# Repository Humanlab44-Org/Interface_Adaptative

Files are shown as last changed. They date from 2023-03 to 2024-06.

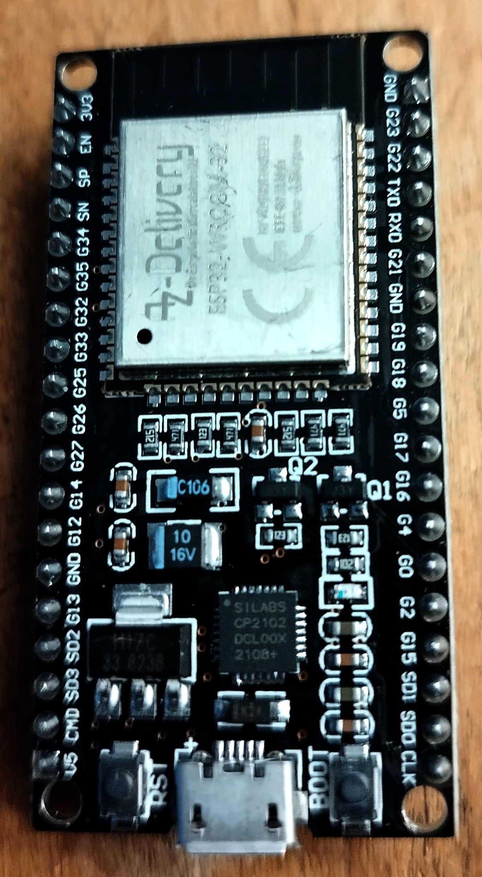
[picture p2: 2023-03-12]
Schema_circuit/esp32.jpg

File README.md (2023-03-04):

# Interface_Adaptative
## Contexte et définition du projet 

Nous projetons de construire une interface de jeux pour personnes aux gestes perturbés ou diminués. En effet, pour celles-ci l’utilisation d’un clavier ou d’une manette de jeux classique est difficile voire impossible à utiliser.  
Ce projet a pour but d’élaborer une première interface dévolue aux jeux vidéo et pouvant évoluer vers un objet de domotique 
## Objectif du projet 

Fourniture d’une première interface fonctionnelle de jeux 

Constitution d’un dossier avec : 

- La procédure d’utilisation, 
- La liste du matériel utilisé,  
- Les plans de fabrication, 
- Les schémas de câblage, 
- Le listing du programme 
- Formation des utilisateurs 
- Ouverture d’une discussion avec les utilisateurs pour l’évolution du projet

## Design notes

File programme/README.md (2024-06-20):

/*
Nom du fichier : readme.md
Auteur : Yann Cesbron  (yann@cesbron.org)
Date de création : 4 avril 2023
Licence :  Creative Commons BY-NC-SA
*/

# HandiPad est une interface de jeux/applications pour personnes aux gestes perturbés ou diminués.
- Ceci permettra l’utilisation d’un clavier/souris et/ou d’une manette de jeux classique.
- Ce programme est operationnel sur ESP32 Wroom ou Wroover. 
- il s'inscrit dans un projet qui a pour but d’élaborer une première interface dévolue aux jeux vidéo et d'autres usages.

- L'interface hardware sera decrite prochainement. Quelques elements sont toutefois disponibles ici: https://github.com/Humanlab44-Org/Interface_Adaptative

# LICENCE
CC-by-nc-sa (Attribution / Pas d’Utilisation Commerciale / Partage dans les mêmes conditions)

La licence CC-by-nc-sa 4.0 permet toute exploitation de l’œuvre (partager, copier, reproduire, distribuer, communiquer, réutiliser, adapter) par tous moyens, sous tous formats. Toutes les exploitations de l’œuvre ou des œuvres dérivées, sauf à des fins commerciales, sont possibles.

Les obligations liées à la licence sont de :
- créditer les créateurs de la paternité des œuvres originales, d’en indiquer les sources et d’indiquer si des modifications ont été effectuées aux œuvres (obligation d’attribution) ;
- ne pas tirer profit (gain direct ou plus-value commerciale) de l’œuvre ou des œuvres dérivées ;
- diffuser les nouvelles créations selon des conditions identiques (selon la même licence) à celles de l’œuvre originale (donc autoriser à nouveau les modifications et interdire les utilisations commerciales).

Cette licence interdit donc que les nouvelles dérivations de l’œuvre dérivée soient exploitées à des fins commerciales.

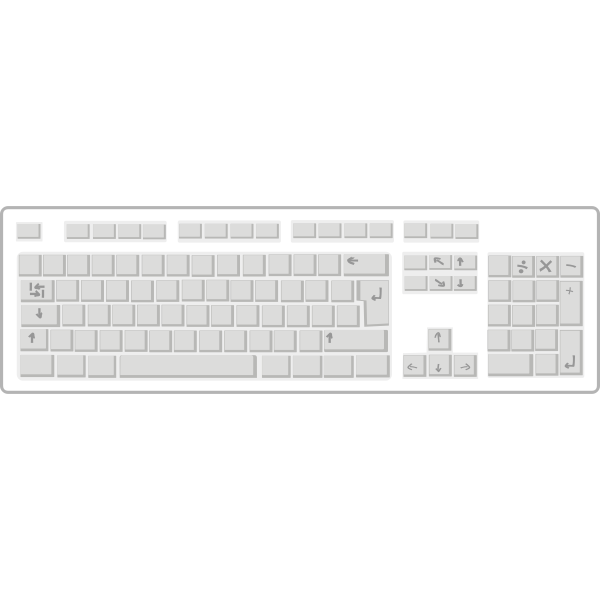
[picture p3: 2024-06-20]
programme/SDCard/img/blank_keyboards.png

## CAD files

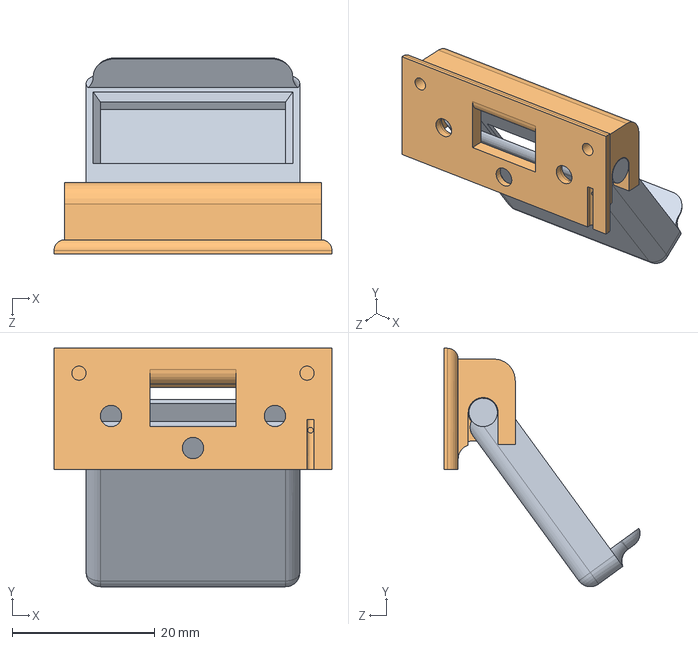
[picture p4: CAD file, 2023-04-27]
Montage3D/Afficheur/Assemblage6.SLDASM
39.0 x 33.5 x 27.5 mm
SupportAff6
Base6

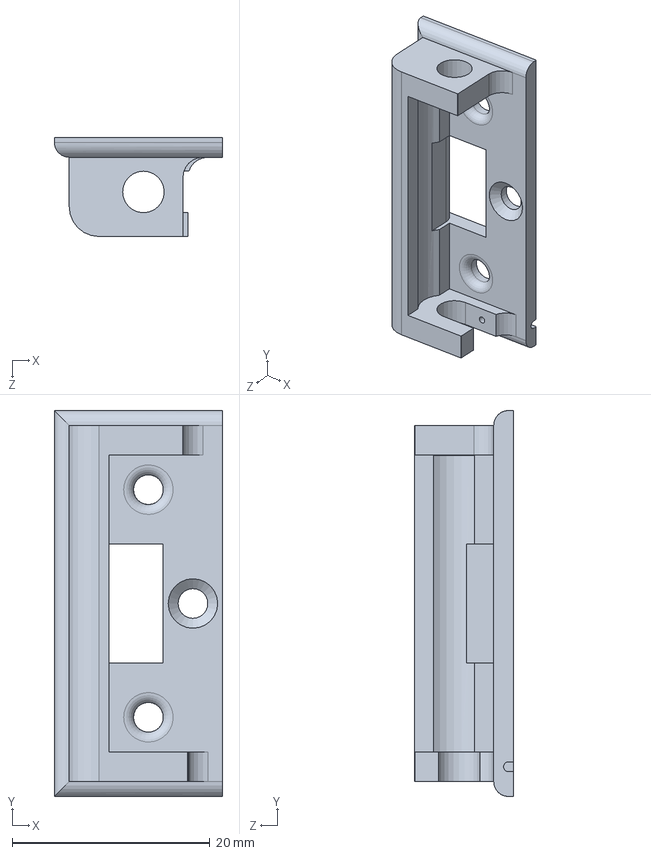
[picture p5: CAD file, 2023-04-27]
Montage3D/Afficheur/Base6.SLDPRT
17.0 x 39.0 x 10.0 mm

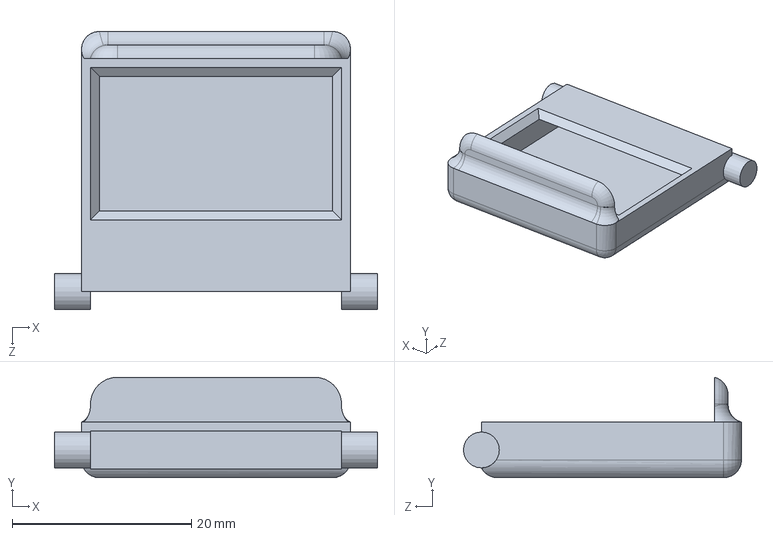
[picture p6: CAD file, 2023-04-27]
Montage3D/Afficheur/SupportAff6.SLDPRT
36.0 x 11.2 x 31.0 mm

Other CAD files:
Montage3D/Afficheur/Base6.STL
Montage3D/Afficheur/SupportAff6.STL

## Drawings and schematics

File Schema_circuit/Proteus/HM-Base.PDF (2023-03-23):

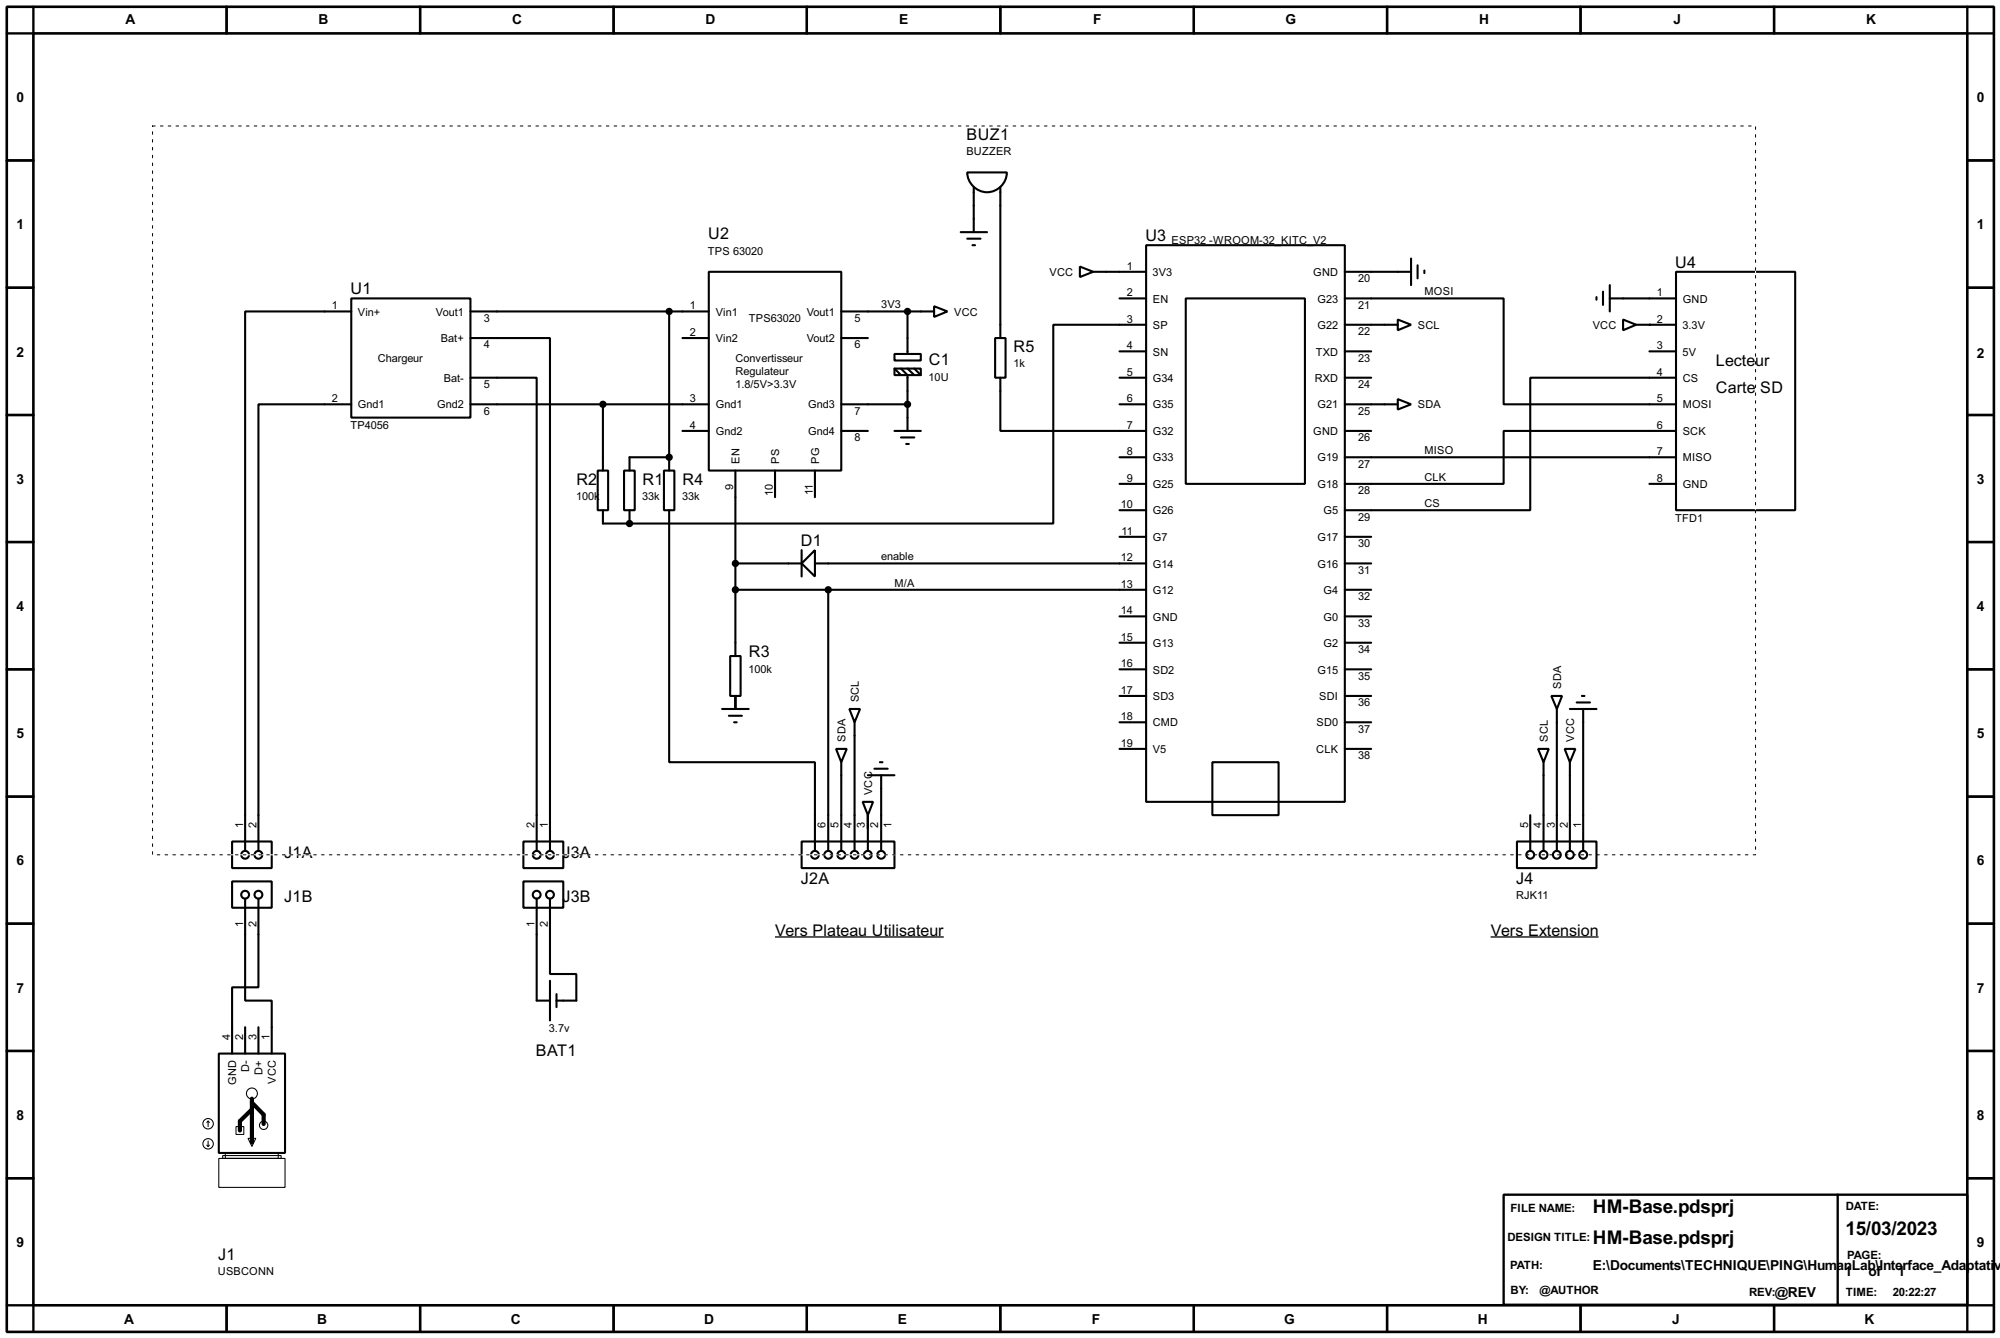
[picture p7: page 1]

BUZ1 BUZZER

2 | 3 Bat+

2 3 | Vout2 Convertisseur 1.8/5V>3.3V Regulateur Gnd1 Gnd3 Gnd2 Gnd4 | 6 Vin2

enable M/A | 31 G4

PAGE: HM-Base.pdsprj

FILE NAME:
DESIGN TITLE:HM-Base.pdsprj

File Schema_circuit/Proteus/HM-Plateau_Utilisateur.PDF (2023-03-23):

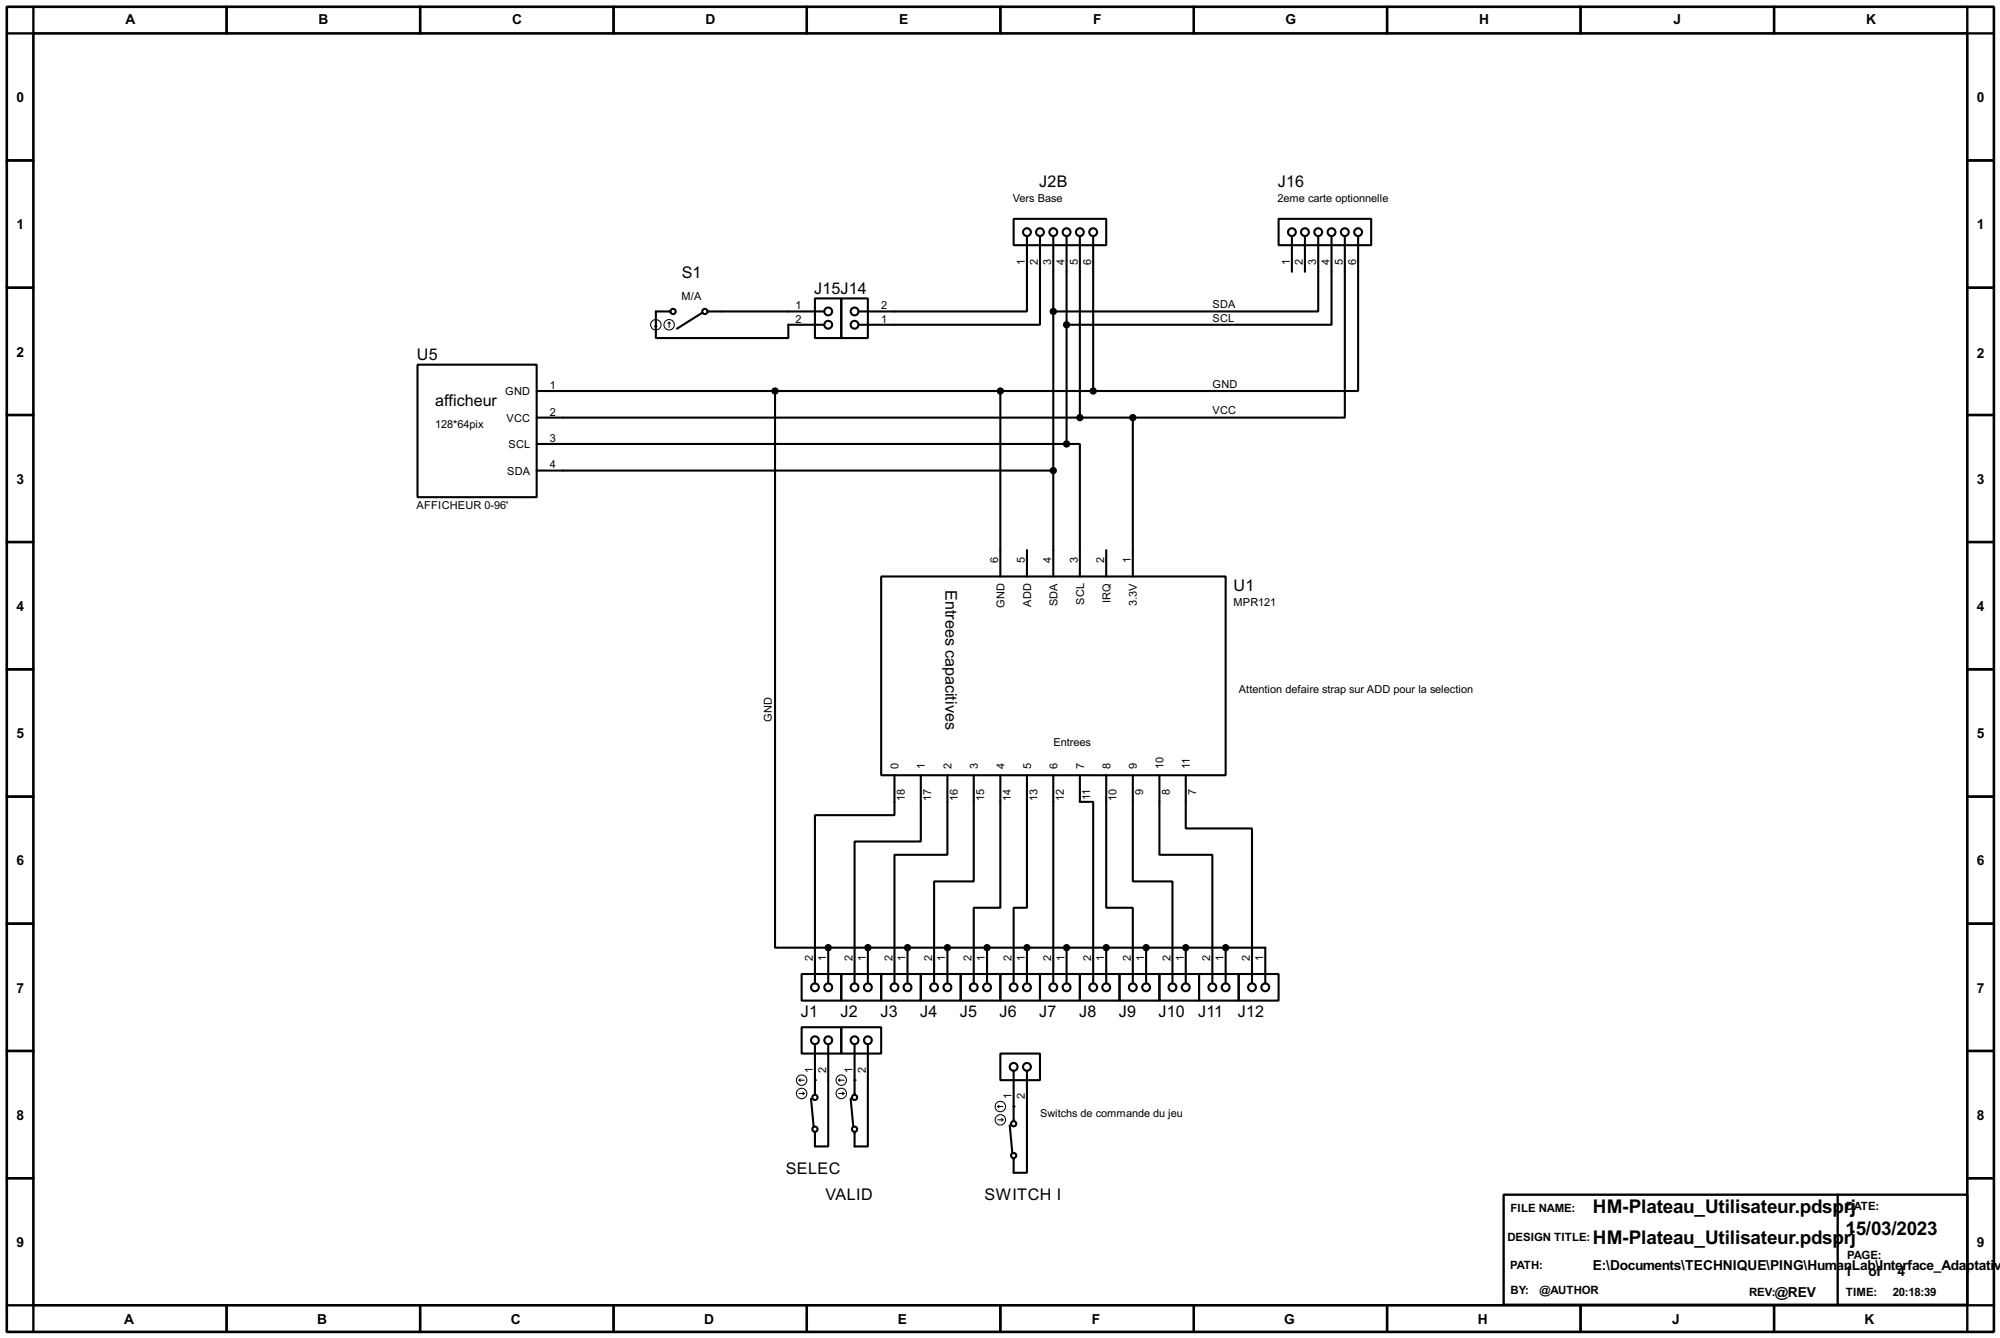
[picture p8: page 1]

1 VCC | | VCC afficheur 128*64pix

GND

2 SCL

3 SDA 4

Attention defaire strap sur ADD pour la selection

Switchs de commande du jeu

FILE NAME:
DESIGN TITLE:HM-Plateau_Utilisateur.pdsprj

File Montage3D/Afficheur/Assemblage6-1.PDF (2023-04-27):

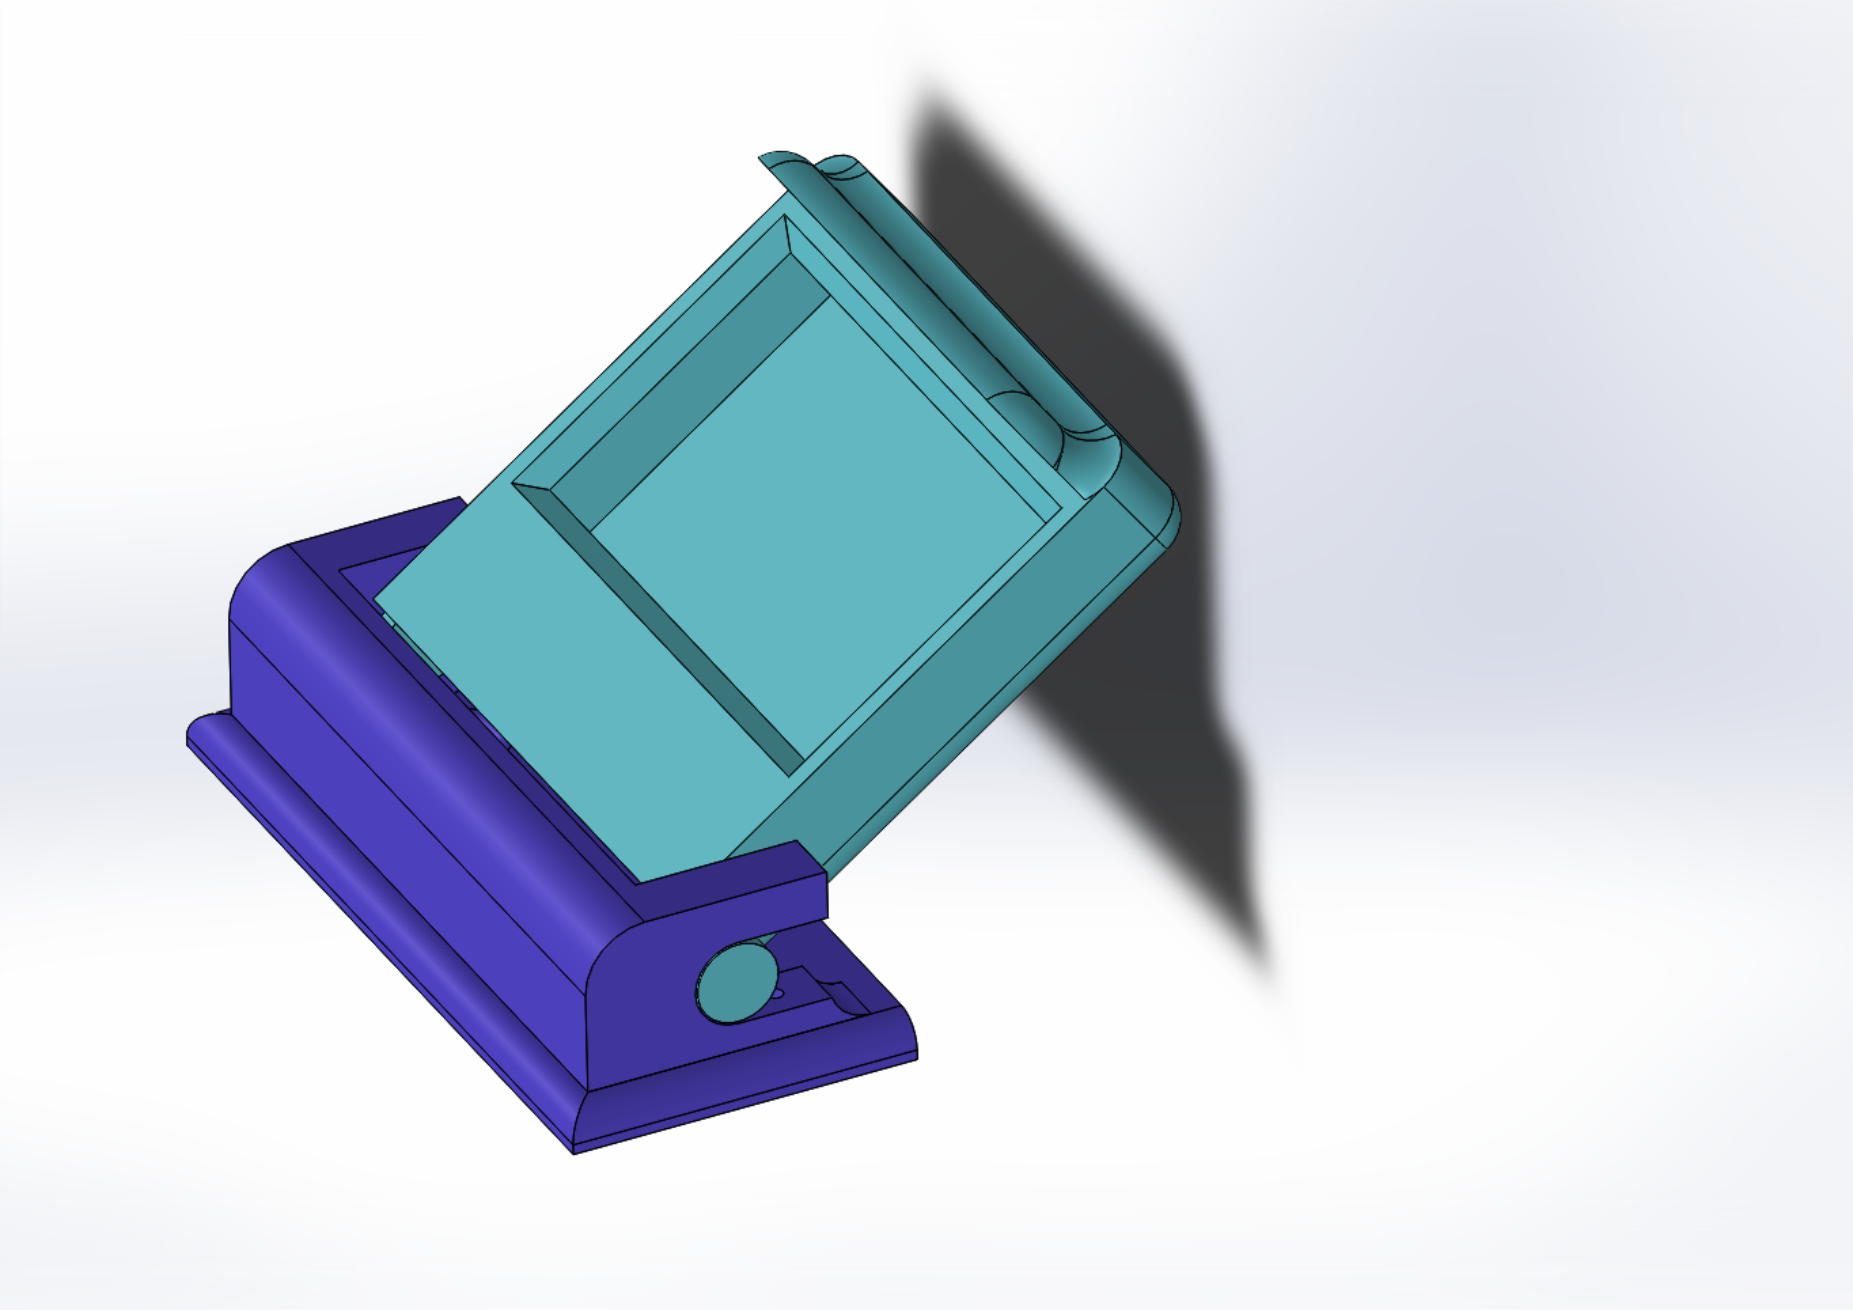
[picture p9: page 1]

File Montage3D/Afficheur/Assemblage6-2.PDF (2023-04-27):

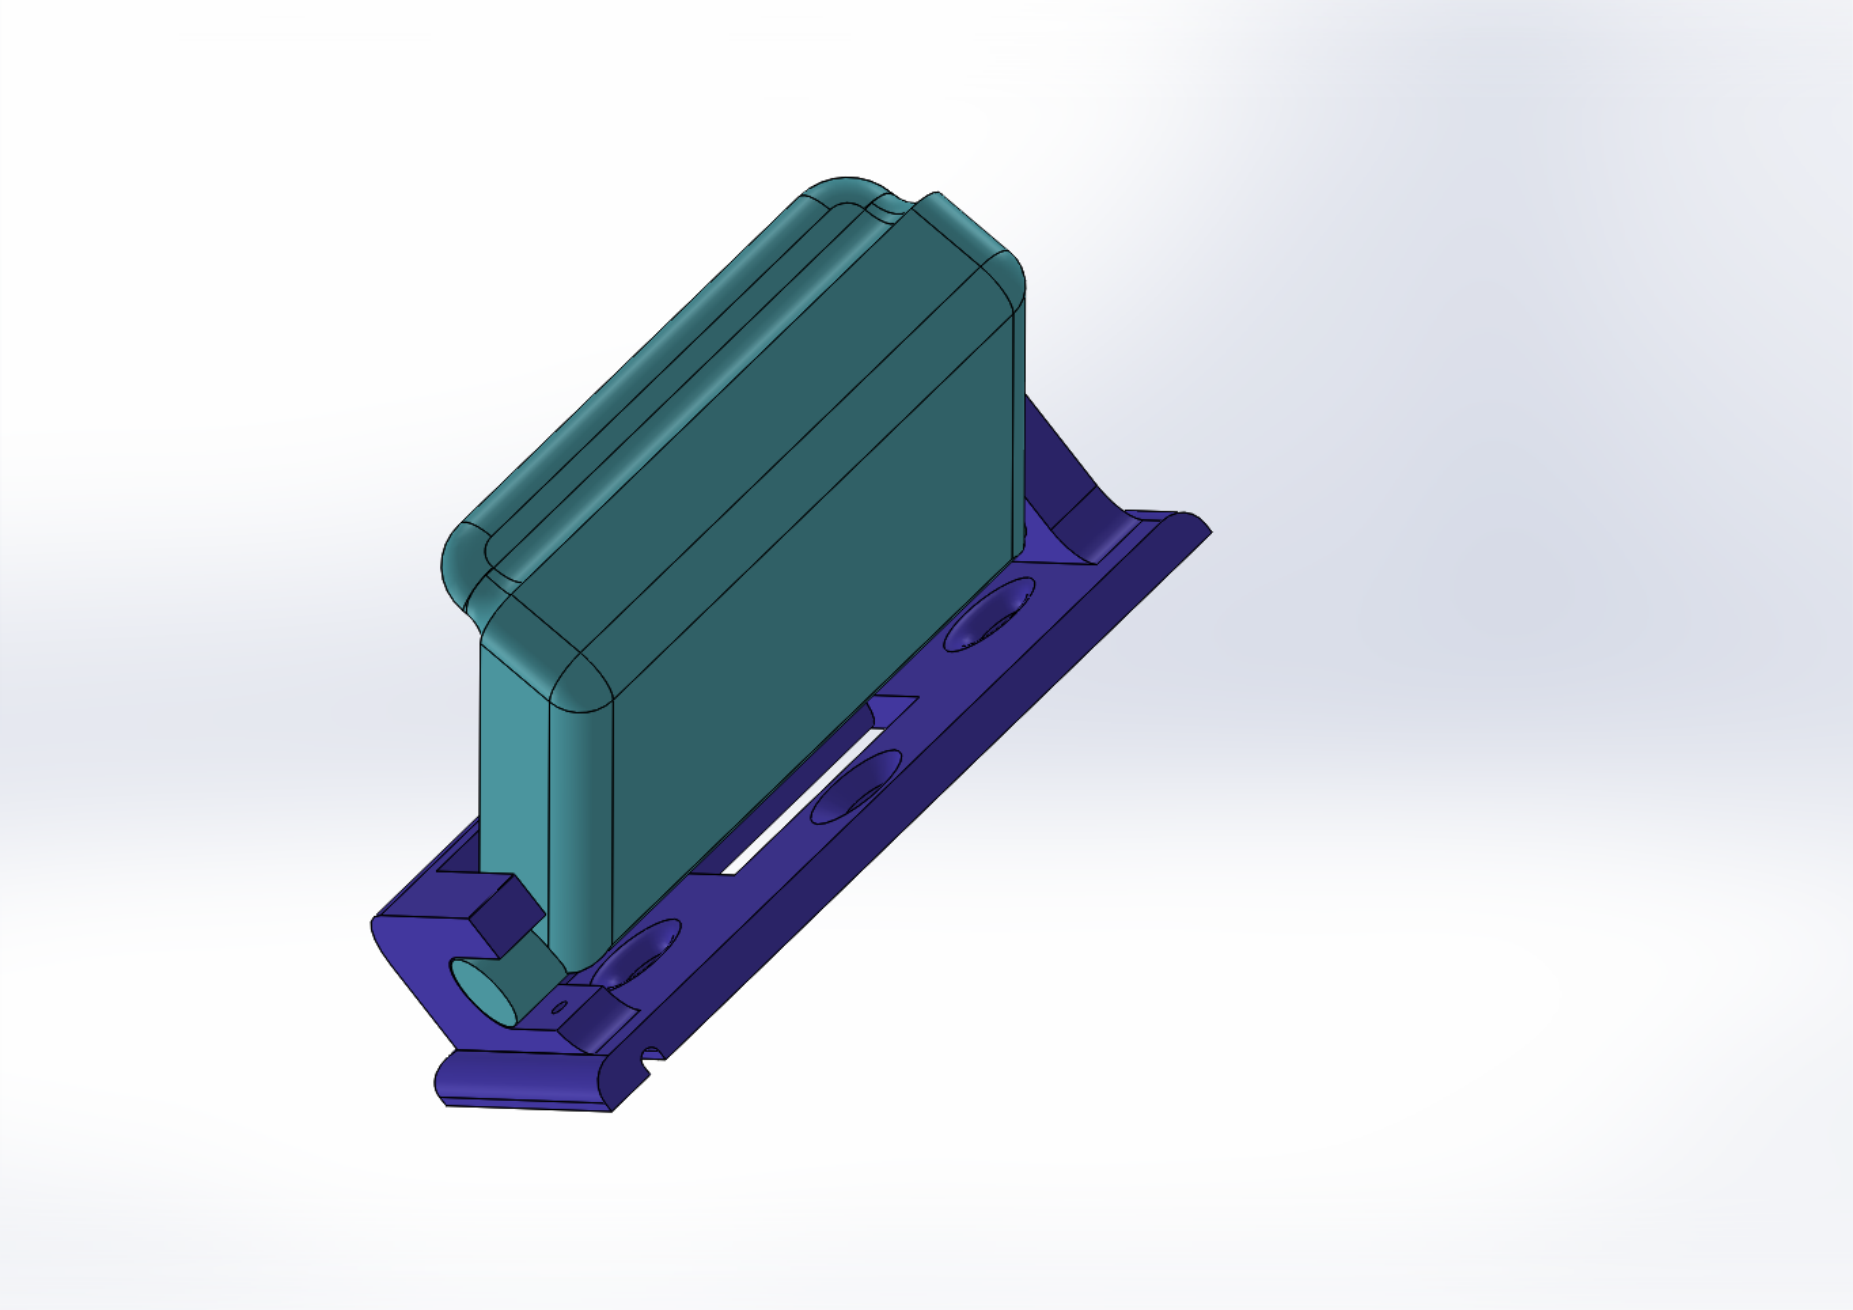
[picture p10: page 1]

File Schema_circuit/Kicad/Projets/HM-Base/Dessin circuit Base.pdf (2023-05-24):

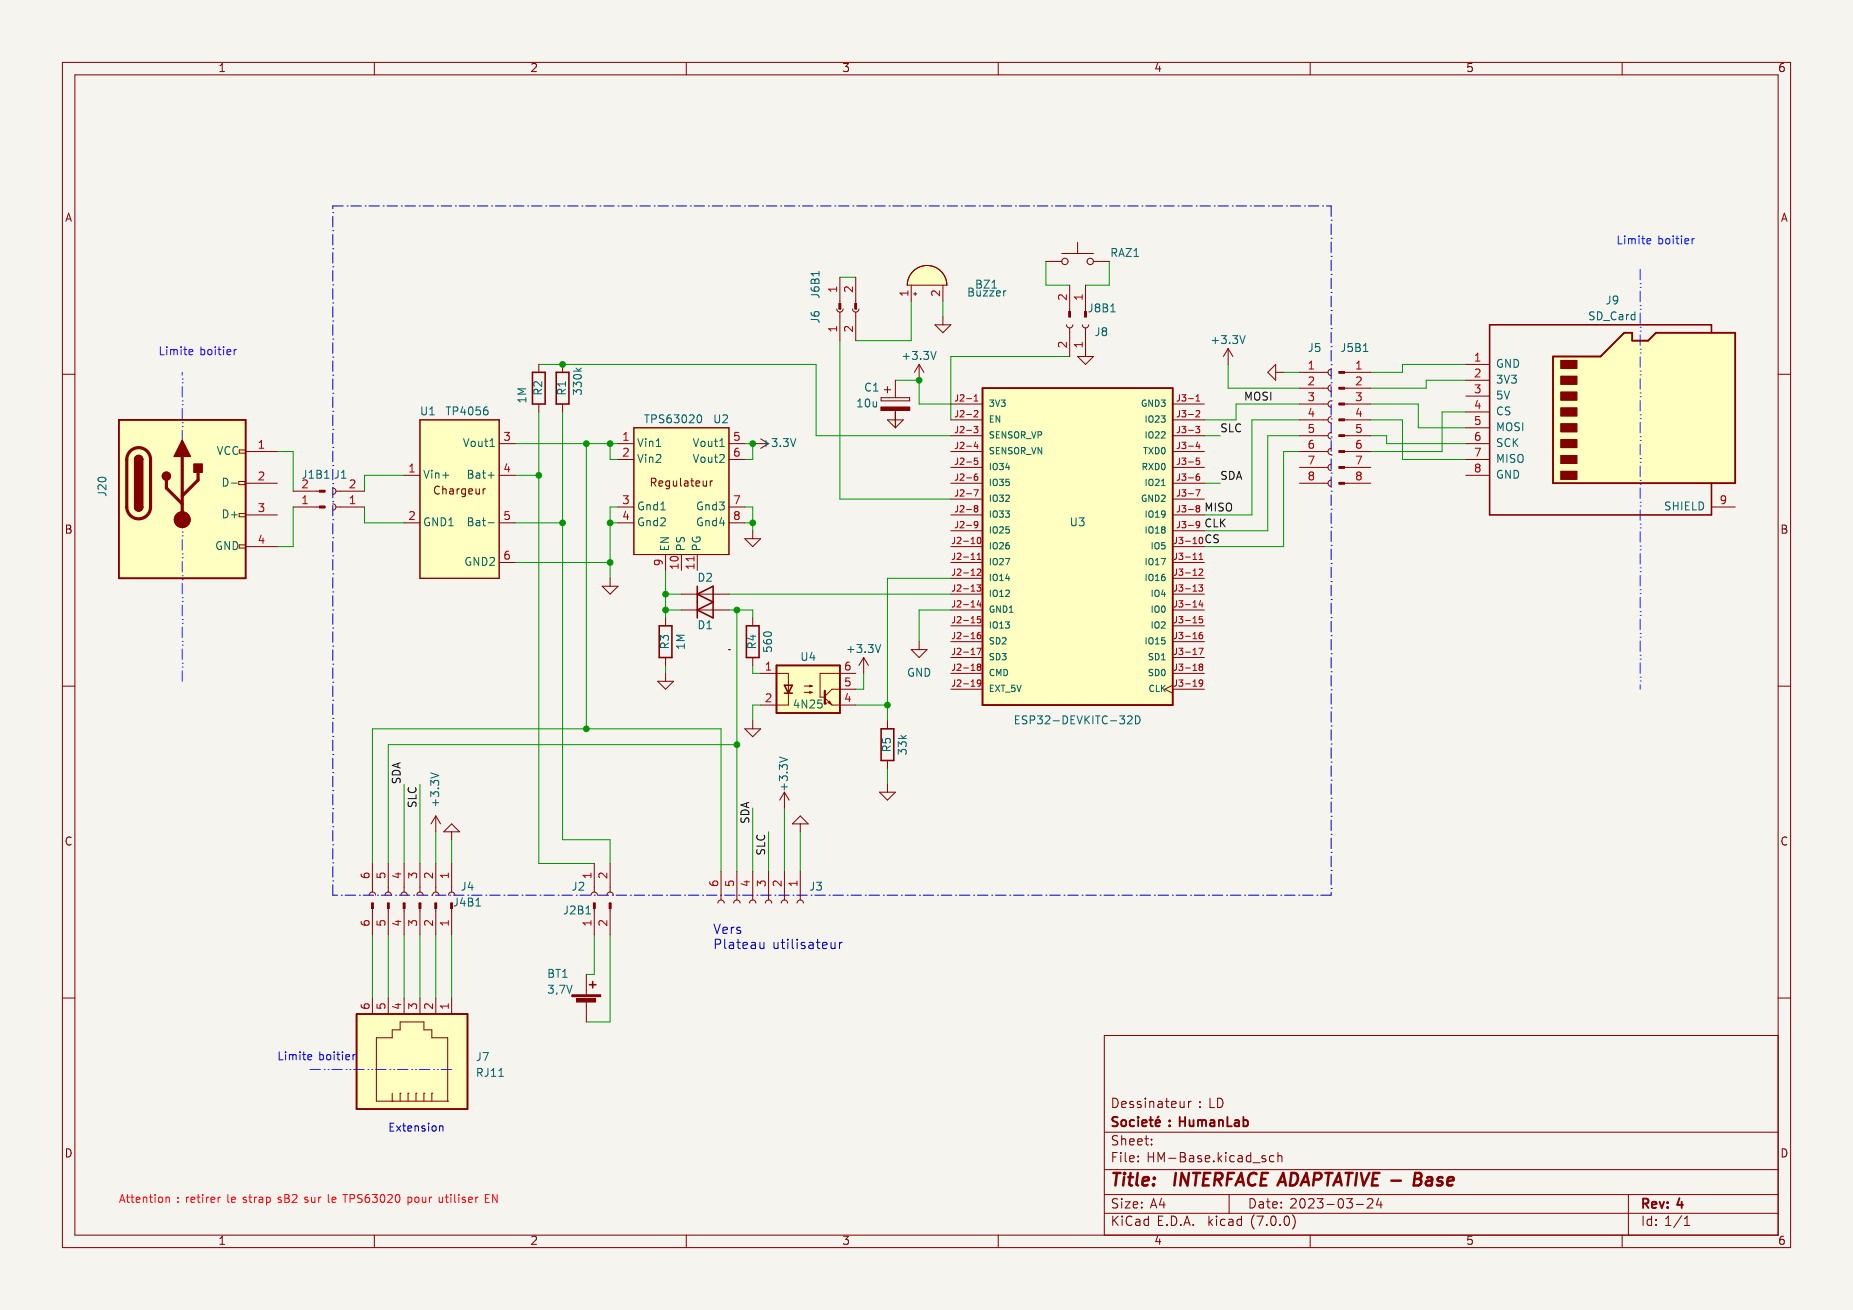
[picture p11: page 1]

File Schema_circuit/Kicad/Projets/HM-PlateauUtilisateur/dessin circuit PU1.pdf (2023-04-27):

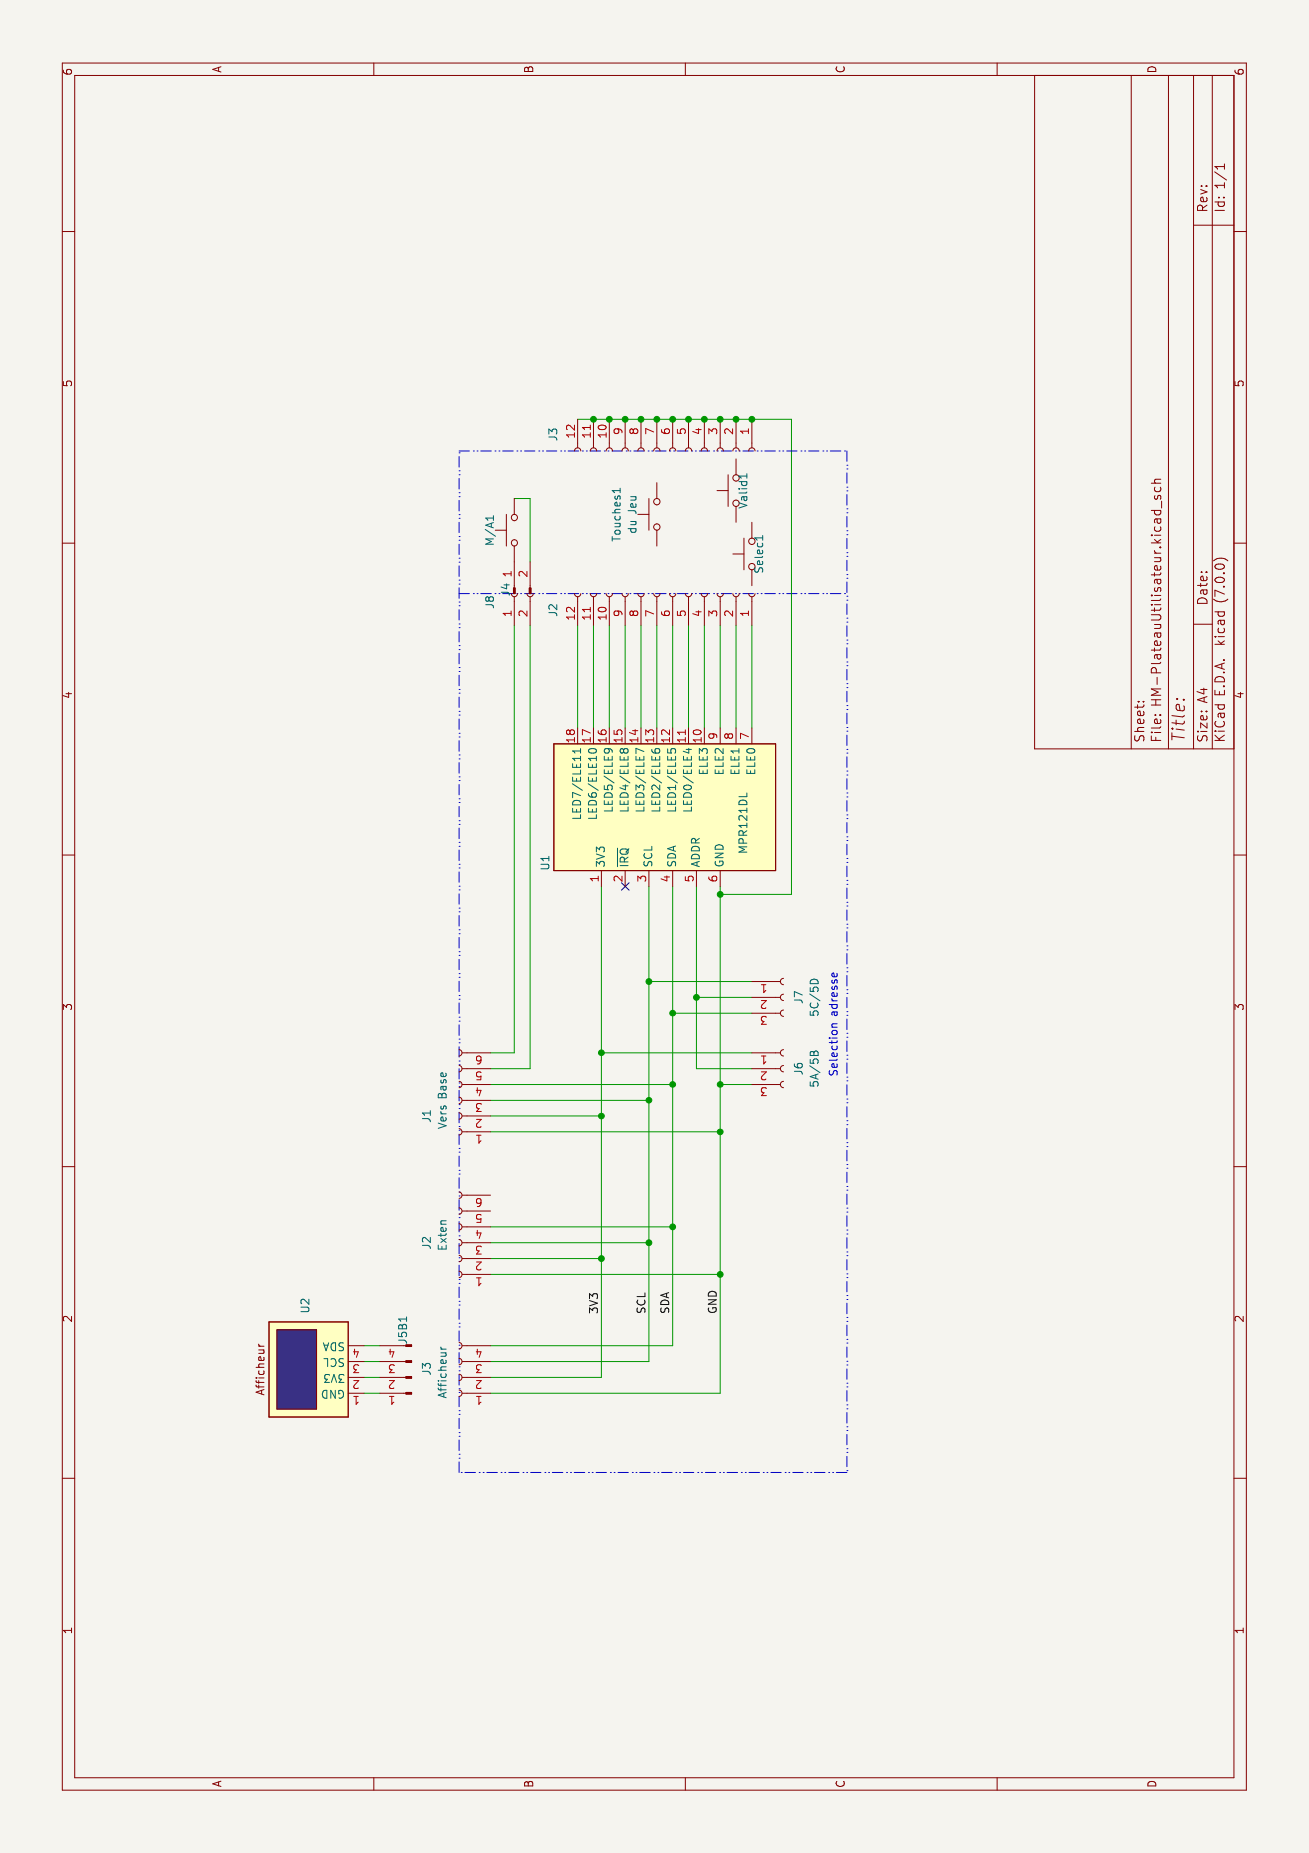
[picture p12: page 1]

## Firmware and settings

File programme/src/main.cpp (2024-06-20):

/*
Nom du fichier : main.ccp
Auteur : Yann Cesbron  (yann@cesbron.org)
Date de création : 4 avril 2023
Licence :  Creative Commons BY-NC-SA
*/

#include "main.h"

/*!
 *  @brief      Setup de main.cpp (framework arduino)
 */
void setup()
{
  //psramInit(); // --------------------------- initialise la PSRAM .. seulement pour un wroover
  powerOn();
  Serial.begin(115200);
  Serial.flush();
  // Serial.print(F("---- debug sur Serial2  TX pin:"));
  // Serial.println(TXD2);
  //  ---------------  debug sur Serial2
  // Serial2.begin(115200, SERIAL_8N1, RXD2, TXD2);
  Serial.println(F("==============================================================="));
  Serial.println(F("---- Starting HumanLab/HandiPad ----"));
  Serial.println(F("==============================================================="));
  // --------------------
  MemoryInfos();
  // infos
  // chip_infos();
  // ----------------init display
  initDisplay();
  // --------------- init  SDcard
  initSDcard();
  // ------------  charge la config systeme
  loadSysConf();
  //  --------- restaure la derniere config clavier
  loadKeysConf();
  MemoryInfos();
  //   ------------  init keySensor
  initKeysSensor();
  // --------------- init bouton on/off
  initPowerButton();
  // start mode BLE = 1 et WIWI = 0 incompatible -> partage meme antenne
  if (getRadioMode() == 0)
  { 
    //  --------------- init wifi & webserver
    initWifi();
    ArduinoOTA.begin();
  }
  else
  { 
    //   -------------  Nunchuck (manette wii)
    initNunchuck();
    //   -------------  init Clavier & souris en Bluetooth
    initBLEKeyboard();
  }

  // --------------- init Timers()
  initTimers();
  MemoryInfos();
}
/*!
 *  @brief      loop de main.cpp (framework arduino)
 *  @param      none
 *  @returns    void
 */
void loop()
{
  handleKeysSensor();
  handlePowerButton();
  if (getRadioMode() != 0)
  { // bluetooth
    handleNunchuck();
  }
  else
  { // wifi
    ArduinoOTA.handle();
  }
  handleTimers();
  delay(10);
  yield();
}

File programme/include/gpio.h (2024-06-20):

/*
Nom du fichier : gpio.h
Auteur : Yann Cesbron  (yann@cesbron.org)
Date de création : 4 avril 2023
Licence :  Creative Commons BY-NC-SA
*/

// ---------------------   GPIO ESP32
// TX = 1;
// RX = 3;


// -- i2c  pour modules
// SDA = 21;
// SCL = 22;
//       affichage  Address; 0x3D for 128x64, 0x3C for 128x32
//       boutons/pad
//          ADDR not connected : 0x5A
//          ADDR tied to 3V : 0x5B
//          ADDR tied to SDA : 0x5C
//          ADDR tied to SCL : 0x5D

// -- spi   pour module carte SD
// SS = 5;
// MOSI = 23;
// MISO = 19;
// SCK = 18;

// -- SS pin SDcard
#define SDCARD_SS_PIN 5

// -- power
#define POWER_BUTTON_PIN 14  // bouton M/A appui bref ON,  appui long (>2s) pour OFF, double clic swicth WIFI/BLE
#define POWER_CMD_PIN 12     // commande du enable régulateur

// -- Serial2 pour debug et pour liberer Serial
#define RXD2 26
#define TXD2 27

// -- buzzer
#define BUZZER_PIN 32 // PWM output

// -- analog tension batterie
#define BATTERY_PIN 36  // analog input

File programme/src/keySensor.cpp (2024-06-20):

#include <keySensor.h>

/*
Nom du fichier : keySensor.ccp
Auteur : Yann Cesbron  (yann@cesbron.org)
Date de création : 4 avril 2023
Licence :  Creative Commons BY-NC-SA
*/

/*!
 *  @brief      Initialisation  sensors  type MPR121
 *  https://www.adafruit.com/product/1982
 *  @param      none
 *  @returns    true/false
 */
bool initKeysSensor()
{
    Serial.println(F("-- Initialisation keySensor :"));
    initBeep();
    // hardware keys sensor
    for (int i = 0; i < NB_SENSOR; i++)
    {
        Serial.print(F("MPR121 address: "));
        Serial.print(keySensorAdr[i], HEX);
        if (!keySensor[i].begin(keySensorAdr[i]))
        {
            Serial.println(F(" non trouve ou erreur"));
        }
        else
        {
            Serial.println(F(" trouve!"));
            nbKeySensorFound++;
            beep();
        }
    }
    Serial.print(F("- > nb MPR121: "));
    Serial.println(nbKeySensorFound);
    int nbHardwareKeys = (nbKeySensorFound * 12) - 2; // Nb max de boutons harware
    setNbKeys(nbHardwareKeys);
    Serial.println("");
    // --------------------- variables pour le fonctionnement  selection/validation
    keySensorContext.bankSelected = 0;
    keySensorContext.runState = false;
    noTmpfileSelected = -1;

    if (nbKeySensorFound > 0)
    {
        return (true);
    }
    else
    {
        return (false);
    }
}
/*!
 *  @brief      // Get the currently touched pads (sensor MPR121)
 *  and call misc cmdKey (int key, bool press/release) if key 0 or 1
 *  else for others
 *  call BLEkeyboard sendKey(int key, bool pressed/released) to send key
 *  @param      none
 *  @returns    none
 */
void handleKeysSensor()
{
    bool keyState;
    for (int y = 0; y < nbKeySensorFound; y++) // boucle sur 3 max
    {
        currtouched[y] = keySensor[y].touched();

        for (int i = 0; i < 12; i++)
        {

            if ((currtouched[y] & _BV(i)) && !(lasttouched[y] & _BV(i)))
            {
                Serial.print(i + (y * 12));
                Serial.println(F(" touche"));
                keyState = PRESSED;
                handleKey(i + (y * 12), keyState);
                if (i + (y * 12) < 2)
                {
                    beep();
                }
            }

            if (!(currtouched[y] & _BV(i)) && (lasttouched[y] & _BV(i)))
            {
                Serial.print(i + (y * 12));
                Serial.println(F(" relache"));
                keyState = RELEASED;
                handleKey(i + (y * 12), keyState);
            }
        }
        lasttouched[y] = currtouched[y];
        delay(PRESS_DELAY);
    }
}
/**
 * @brief   // look if the key is cmd or keyboard key
 * @param keyID
 * @param keyState
 */
void handleKey(int keyID, bool keyState)
{
    if (keyID < 2) // touches de commande
    {
        handleKeySensorContext(keyID, keyState);
        // Serial.println(F(" touche de commande"));
    }
    else
    {
        if (keySensorContext.runState == 1) // envoi uniquement en mode run
        {
            sendKey(keySensorContext.bankSelected, keyID - 2, keyState); // dans SDCard
            // Serial.println(F(" touche clavier/pad"));
        }
    }
    PowerOffTimer(ON); // restart le timer powerOFF
}

/**
 * @brief   // manage select & valid keys
 * @param keyID
 * @param keyState
 */
void handleKeySensorContext(int keyID, bool keyState)
{
    if (keyState == PRESSED)
    {
        switch (keySensorContext.runState)
        {
        case 0: // mode select file
            switch (keyID)
            {
            case 0: // selection
                noTmpfileSelected += 1;
                if (noTmpfileSelected >= nbconfKeys)
                {
                    noTmpfileSelected = 0;
                }
                Serial.print(F(" ---------- fichier app ou jeu selectionne: "));
                Serial.print(noTmpfileSelected);
                Serial.print(F(" "));
                Serial.println(confKeysFilenames[noTmpfileSelected]);
                fileSelected = confKeysFilenames[noTmpfileSelected];
                fileSelected = fileSelected.substring(0, fileSelected.lastIndexOf('.'));
                displayMsg("Selection APP/JEU \n" + fileSelected, 0, 0); // TODO    à reprendre avec l'affichage
                break;

            case 1: // validation
                if (noTmpfileSelected >= 0)
                {
                    // changement  nouvelle config
                    if (!setDefaultCfg((String)confKeysFilenames[noTmpfileSelected])) // dans SDCard
                    {                                                                 // erreur read or not exist
                        keySensorContext.runState = 1;                                // force le mode selection de fichier
                        noTmpfileSelected = -1;
                        break;
                    }
                    keySensorContext.bankSelected = 0;
                }
                // noTmpfileSelected = -1;
                keySensorContext.runState = 1;
                startApp(); // envoie la sequence de start // dans SDCard
                Serial.println();
                Serial.println(F(" ------> On passe en mode choix banque: "));
                
                Serial.print(F(" banque en cours: "));
                Serial.print(keySensorContext.bankSelected);
                Serial.print(" ");
                Serial.println(getBankName(keySensorContext.bankSelected));
                displayMsg(getProgramName() + "\n" + getBankName(keySensorContext.bankSelected), 0, 0); // TODO    à reprendre avec l'affichage
                break;
            default:
                break;
            }
            break;
        case 1: // mode run
            switch (keyID)
            {
            case 0: // selection  bank
                keySensorContext.bankSelected += 1;
                if (keySensorContext.bankSelected >= nbBanks)
                {
                    keySensorContext.bankSelected = 0;
                }
                Serial.print(F(" banque de touche selectionnee: "));
                Serial.print(keySensorContext.bankSelected);
                Serial.print(" ");
                Serial.println(getBankName(keySensorContext.bankSelected));
                displayMsg(getProgramName() + "\n" + getBankName(keySensorContext.bankSelected), 0, 0); // TODO    à reprendre avec l'affichage
                break;
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

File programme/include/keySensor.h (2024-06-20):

/*
Nom du fichier : keySensor.h
Auteur : Yann Cesbron  (yann@cesbron.org)
Date de création : 4 avril 2023
Licence :  Creative Commons BY-NC-SA
*/

#include <Wire.h>
#include <ArduinoJson.h>
#include "Adafruit_MPR121.h"
#include "gpio.h"

#ifndef _BV
#define _BV(bit) (1 << (bit))
#endif
#define ON true
#define OFF false
#define PRESS_DELAY  20  // ms

bool initKeysSensor();
void handleKeysSensor();
void handleKey(int keyID, bool keyState);
// ADDR tied to GND : 0x5A   (default.. cut the thin track before short another)
// ADDR tied to 3V : 0x5B
// ADDR tied to SDA : 0x5C
// ADDR tied to SCL : 0x5D
#define NB_SENSOR 3
int nbKeySensorFound = 0;
uint16_t keySensorAdr[3] = {0x5A, 0x5B, 0x5C};
Adafruit_MPR121 keySensor[3] = {Adafruit_MPR121(), Adafruit_MPR121(), Adafruit_MPR121()};

#define PRESSED 1
#define RELEASED 0

// Keeps track of the last pins touched
// so we know when buttons are 'released'
uint16_t lasttouched[NB_SENSOR];
uint16_t currtouched[NB_SENSOR];

struct ksc
{
    int runState;     // run = 1
    int bankSelected; //
};
ksc keySensorContext;
int noTmpfileSelected;
String fileSelected;

    int extern nbBanks;              // mis à jour par SDCard.cpp
int extern nbconfKeys;               // mis à jour par SDCard.cpp
char extern confKeysFilenames[][25]; // mis à jour par SDCard.cpp

// ---------------- fonctions
void handleKeySensorContext(int, bool);
void extern sendKey(int banque, int touche, int keyState); // dans SDCard
void extern PowerOffTimer(bool);                           // dans power
String extern getBankName(int);                            // dans SDCard
String extern getProgramName();                            // dans SDCard
bool extern setDefaultCfg(String fileName);                 // dans SDCard
void extern startApp();                                    // dans SDCard
void extern stopApp();                                     // dans SDCard
bool extern setNbKeys(int);                                // dans SDCard
void extern initBeep();                                     // dans misc
void extern beep();                                         // dans misc
void extern displayMsg(String, int, int);               // dans display

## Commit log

2023-03-01 ajout du modele de fichier de config
2023-03-04 ajout des codes pour 2 jeux de test
    Les jeux Bejeweled et Burnin Rubber ont été ajouté au fichier abcd.json
    - les codes touches flèches sont à corriger
    - code "barre espace" à ajouter
2023-03-04 Ajout fichier des touches speciales
    la valeur décimale de 'value' est à mettre pour la touche (à terme, le configurateur embarqué fera tout ce travail)
2023-03-04 Mise à jour codes pour les flèches
2023-03-04 Correction erreur de parsing
    Erreur de syntaxe corrigée, manquait des ","
2023-03-12 Fichier des jeux mis à jour
    Le format a été modifié mais reste compatible avec les anciennes versions..
    le nom de la touche a ete ajouté avec la sensibilité.
    Les ID ont été supprimés...
2023-03-23 Schemas sous Kicad
    [HM-Base.kicad_pcb, HM-Base.kicad_sch, HM-PlateauUtilisateur.kicad_pcb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]
2023-03-24 Rectification schema BASE
    [HM-Base.kicad_pcb, HM-Base.kicad_sch]
2023-03-29 MaJ 29-04-23
    [HM-Base.kicad_sch]
2023-03-30 Circuits archivés
2023-03-31 correctif sur PCB PU1
    [HM-PlateauUtilisateur-B_Cu.gbr, HM-PlateauUtilisateur-B_Mask.gbr, HM-PlateauUtilisateur-B_Paste.gbr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]
2023-04-02 MaJ PCB Base v4
2023-04-21 MaJ Base
    [HM-Base-B_Cu.gbr, HM-Base-B_Paste.gbr, HM-Base-B_Silkscreen.gbr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]
2023-04-21 MaJ Afficheur
    [Assemblage1.SLDASM, Assemblage2.SLDASM, Assemblage5.SLDASM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]
2023-04-27 Nettoyage et MàJ dossier Schema_circuit
    [HM-Base-B_Cu.gbr, HM-Base-B_Paste.gbr, HM-Base-B_Silkscreen.gbr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]
2023-04-27 Nettoyage et MàJ Afficheur
    [Assemblage1.SLDASM, Assemblage2.SLDASM, Assemblage5.SLDASM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]
2023-05-24 MàJ schema et PCB
